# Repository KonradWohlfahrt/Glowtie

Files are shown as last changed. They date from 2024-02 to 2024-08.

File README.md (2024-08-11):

# Glowtie
This repository contains the project files for the Glowtie, a bowtie with individually addressable LEDs.
It was originally designed by [Stephen Hawes](https://github.com/sphawes/glowtie).
At the beginning, I used [Raxathor's](https://github.com/raxathor/GlowTie) adaptation.
Due to the lack of documentation, especially where to place the smd components, it was a real struggle to build it. Furthermore, I discovered issues with the design and thus settled on creating my own version.
In the following, I'm going to explain how you can build Raxathor's adaptation and of course mine!
Let's get started!

***
# Raxathor's Adaptation
Check out the instructable from [Raxathor](https://www.instructables.com/GlowTie/).

**Materials:**
| Component |  Amount  |
|:---|---:|
| custom pcb | 1 |
| lipo battery (max size: 20 x 30 x 7mm) | 1 |
| ESP-12F | 1 |
| TP4056A | 1 |
| DW01-A | 1 |
| FS8205A | 1 |
| TC2117-3.3V ~~AMS1117 3.3V~~ | 1 |
| SMD Power Slide Switch | 1 |
| Micro USB | 1 |
| WS2812b LEDs (Neopixel) | 13 |
| 10k 0805 | 5 |
| 1k 0805 | 3 |
| 100r 0805 | 1 |
| 10k ~~1.2k~~ 0805 (charge progamming resistor, check TP4056A datasheet) | 1 |
| red LED 0805 | 1 |
| green LED 0805 | 1 |
| 0.1uF 0805 | 2 |
| 10uF 0805 | 2 |
| 1uF 0805 | 1 |
| 100uF 1206 | 1 |

**Soldering:**
Solder the components to the indicated boxes on the images.
Make sure to program your chip in advance or add some programming cables to the back.
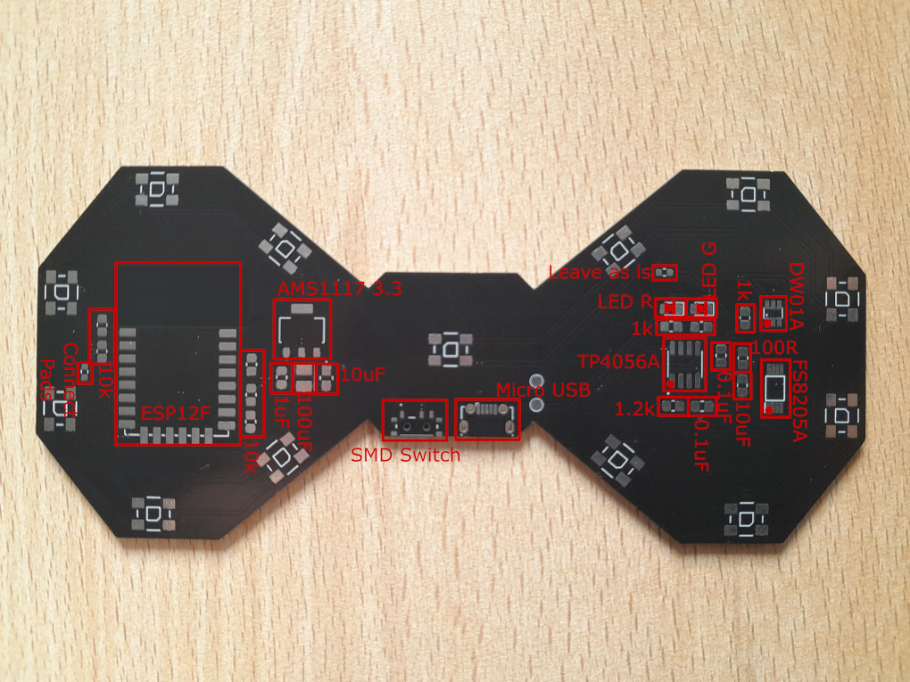
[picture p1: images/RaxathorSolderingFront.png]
Soldering Front

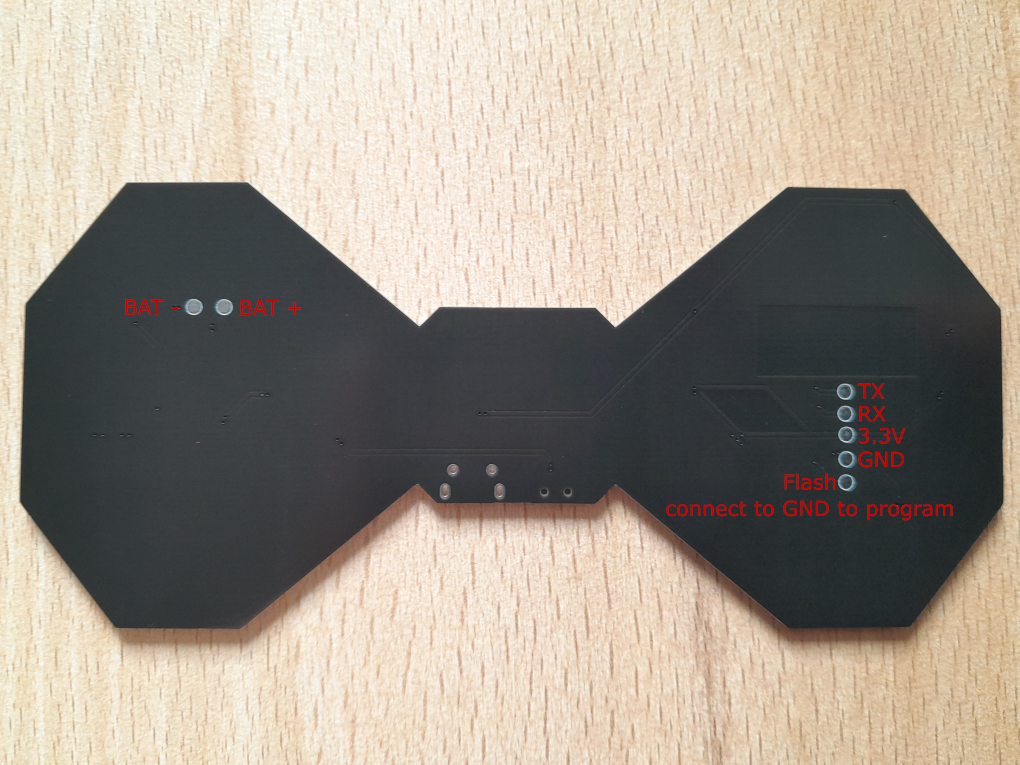
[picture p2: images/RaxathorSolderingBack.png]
Soldering Back


**Issues:**
During my tests I discovered a few flaws with the design.

First of all, the AMS1117 LDO has a too high dropout voltage.
This LDO is not suitable for powering the bowtie!
My alternative is the TC2117. Stephen Hawes used an MCP1826S with only 250mV of dropout. 
However, the pinout of this LDO does not fit on Raxathor's pcb.

Furthermore, soldering with a soldering iron was possible but challenging.
Especially with the small pins of the FS8205A Mosfet.
My smd switches (I've tried muliple) wouldn't always work correctly.
I also had issues with the 3d printed case, as it was not able to secure the pcb for a long amount of time.

***
# My Adaptation
That's why I created my own Glowtie. Those are all the changed I made:
- replaced charging circuit with popular charging board (easier to solder)
- added PH2.0 connector for LiPo battery
- replaced smd with through-hole switch
- added holes for M3 screws to secure the pcb on the 3d print
- new LDO (MIC39100), identical to the pinout of the one used by Stephen Hawes
- voltage divider to measure the voltage of the LiPo battery
- resistor from esp to first led, to prevent damage by high current
- added a button
- better programming pins
- every led has its own capacitor as recommended in the datasheet

However, I've recently discovered a flaw with my design.
The bowtie is not balanced, as the weight of the battery drags it down.
You should put some small objects of equal size inside the other hole.

**Materials:**
| Component | Amount | Silkscreen label |
|:---|:---:|---:|
| custom pcb | 1 | - |
| lipo battery (max size: width=30 x depth=40 x height=7mm) | 1 | - |
| ESP-12F | 1 | U4 |
| LiPo charge board | 1 | U3 |
| MIC39100 | 1 | U5 |
| Switch | 1 | U1 |
| button | 1 | U7 |
| Micro USB | 1 | U2 |
| WS2812b LEDs (Neopixel) | 13 | LED1 - LED13 |
| 100nF 0805 | 14 | C1 - C13, C17 |
| 10uF 0805 | 1 | C14 |
| 1uF 0805 | 1 | C15 |
| 100uF 1206 | 1 | C16 |
| 10k 0805 | 6 | R1 - R4, R6, R8 |
| 33k 0805 | 1 | R5 |
| 220r 0805 | 1 | R7 |
| PH2.0 2p (not recommended -> takes up space) | 1 | U6 |
| 90 degree connector 5p | 1 | - |
| 3d printed case | 1 | - |
| M3x8 screw with nut | 2 | - |

**Soldering:**
Solder the components as indicated in the table and images.
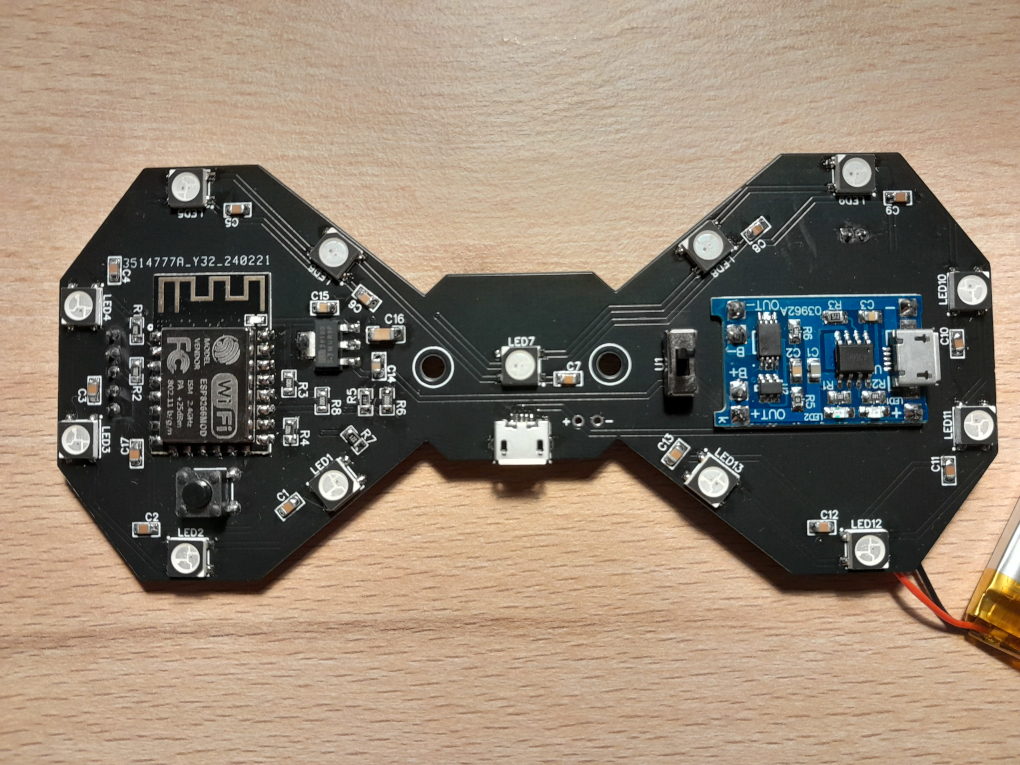
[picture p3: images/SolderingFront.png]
Soldering Front

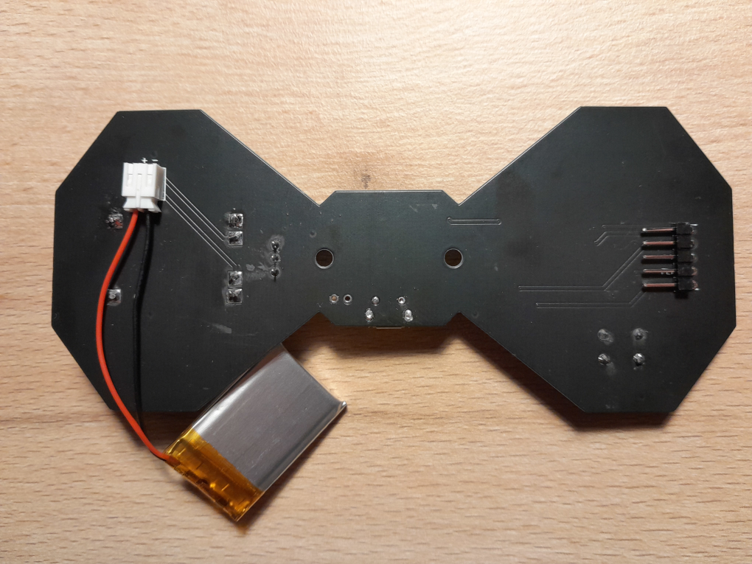
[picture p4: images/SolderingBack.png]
Soldering Back

Also check your datasheet of the battery. The charging board is commonly used for 18650 batteries.
However, the charging current of 1A is not suitable for the batteries used here.
Here's a great [video](https://www.youtube.com/watch?v=6asCEBm4ZAw) showing how you can change the charging resistor (I've used 5.1k 0805).

***
# Programming (for both designs)
In the `src/` folder you'll find my versions of the source code for each pcb design.
Open `Glowtie.ino` and change the ssid and password of the access point to your preferences.
Install the `Adafruit Neopixel` library and the `ESP8266` board manager. For the board select: `NodeMCU 0.9 (ESP-12 Module)`.
Connect the Glowtie with a FTDI programmer (3.3V logic level) like this and upload the code:
- TX (Glowtie) => RX (FTDI)
- RX (Glowtie) => TX (FTDI)
- VCC (Glowtie) => VCC (FTDI)
- GND (Glowtie) => GND (FTDI)
- Flash (Glowtie) => GND (FTDI)
> If you did not connect flash to gnd, the chip will no be in programming-mode. In my design you may just hold down the button while plugging in the FTDI programmer.

***
# The end
Great, now you have yourself your own Glowtie!
There is an enclosure which you can print in a 3d-printer.
I've used two M3x8 screws to secure the pcb on the print.

Button functions:
- short press: show current battery percentage
- double press: toggle random mode (on: green flash, off: red flash)
- long press: save current mode and color to eeprom  

Remember to check out Stephen Hawes and Raxathor, as this repository is based on theirs.

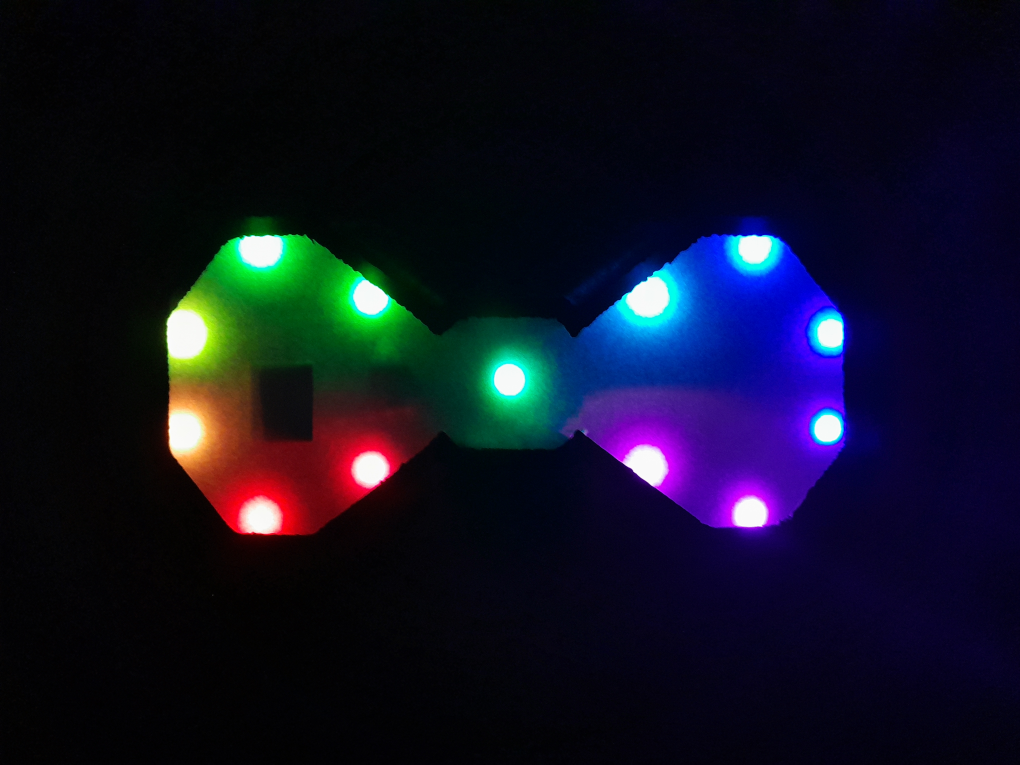
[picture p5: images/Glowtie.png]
Glowtie


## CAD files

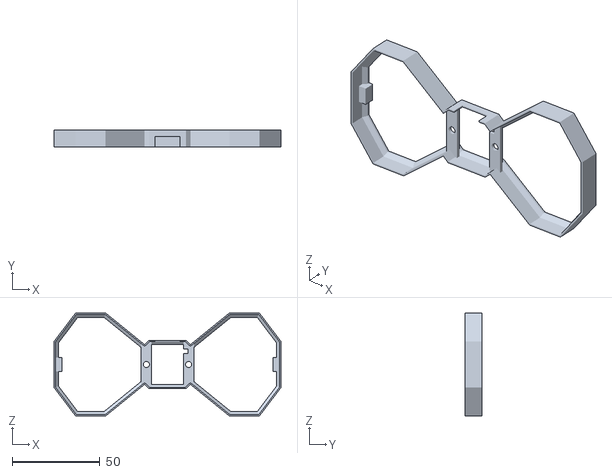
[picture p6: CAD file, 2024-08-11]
cad/Bumper.stl
129.0 x 9.75 x 58.5

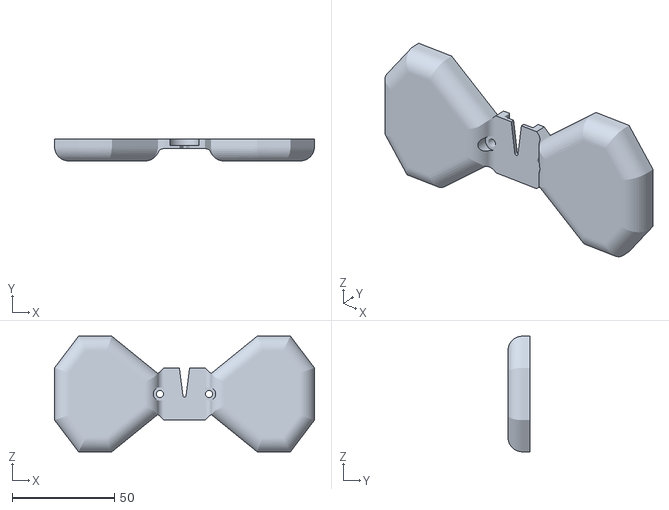
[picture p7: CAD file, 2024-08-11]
cad/Glowtie.stl
127.0 x 10.8 x 56.5

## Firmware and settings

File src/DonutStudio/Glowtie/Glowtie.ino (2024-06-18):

#include <Adafruit_NeoPixel.h>
#include <ESP8266WiFi.h>
#include <WiFiClient.h>
#include <ESP8266WebServer.h>
#include <EEPROM.h>

#include "webserver.h"

#define BUTTONPIN 0
#define SAVETIME 1500
#define DOUBLEPRESSINTERVAL 400

#define PIN 12
#define NUMPIXELS 13
#define EFFECTREFRESHTIME 75

#define BATTCHECKTIME 10000
#define BATTREADINGS 10

#define LOWBATTERYVALUE 825
#define SHUTDOWNVALUE 815


const char *ssid = "Glowtie";
const char *password = "pleaseletmein";

const uint32_t red = 0xff0000;
const uint32_t green = 0x00ff00;

const byte brightness[] = { 10, 20, 30, 40 };
const unsigned long randomTimeMin[] = { 120000, 60000, 30000, 10000 };
const unsigned long randomTimeMax[] = { 360000, 120000, 60000, 20000 };


Adafruit_NeoPixel pixels = Adafruit_NeoPixel(NUMPIXELS, PIN, NEO_GRB + NEO_KHZ800);
ESP8266WebServer server(80);


byte brightnessIndex = 1;


byte redValue = 127;
byte greenValue = 127;
byte blueValue = 127;

bool isRandomMode = false;
bool chooseRandomColor = false;
int speedIndex = 1;
unsigned long randomWait;
unsigned long lastRandomUpdate = 0;

unsigned long lastBatteryCheck = 0;
unsigned long lastEffectUpdate = 0;

unsigned long lastButtonPress = 0;
bool awaitingDoublePress = false;



/* --- UTILITY START --- */

float getVoltage() { return 4.3f / 1023 * analogRead(A0); } // formular: Vbat = (R6 + R5) / (R6 * 1023) * analogRead(A0)
int getBatteryPercent() { return (int)(((float)(analogRead(A0)) - LOWBATTERYVALUE) / (1023 - LOWBATTERYVALUE) * 100); }
bool checkBattery(int minimum)
{
  int avg = 0;
  for (byte b = 0; b < BATTREADINGS; b++)
  {
    avg += analogRead(A0);
    delay(2);
  }
  return (avg / BATTREADINGS) <= minimum;
}

/* --- UTILITY END --- */



#include "LedEffect.h"

#include "Solid.h"

#include "Breathe.h"
#include "Pulse.h"
#include "Bar.h"
#include "Burst.h"

#include "Infinity.h"
#include "Chaser.h"
#include "Circles.h"
#include "Symmetry.h"

#include "Starfield.h"
#include "Rainbow.h"
#include "Filler.h"

const byte effectCount = 19;
LedEffect * effects[] = { new Solid(), new SolidRainbow(),
                          new Breathe(), new Pulse(), new Bar(), new BurstIn(), new BurstOut(), 
                          new Infinity(), new InfinityFill(), new Chaser(), new ChaserFill(), new Circles(), new CirclesFill(), new Symmetry(), new SymmetryFill(),
                          new Starfield(), new Rainbow(), new RainbowFill(), new Filler() };
byte modeIndex = 0;
int effectCounter = 0;

void setup() 
{
  pinMode(A0, INPUT);
  pinMode(BUTTONPIN, INPUT);


  EEPROM.begin(7);
  delay(250);
  modeIndex = constrain(EEPROM.read(0), 0, effectCount - 1);
  redValue = EEPROM.read(1);
  greenValue = EEPROM.read(2);
  blueValue = EEPROM.read(3);

  chooseRandomColor = EEPROM.read(4) == 0;
  speedIndex = constrain(EEPROM.read(5), 0, 3);
  brightnessIndex = constrain(EEPROM.read(6), 0, 3);


  pixels.begin();
  pixels.setBrightness(brightness[brightnessIndex]);

  // ssid, password, default channel, do not hide ssid, one simultaneous connections
  if (WiFi.softAP(ssid, password, 1, false, 1)) 
    scrollAnim(green);
  else
    flashAnim(red);

  server.on("/", handleRoot);
  server.on("/red", handleGetRed);
  server.on("/green", handleGetGreen);
  server.on("/blue", handleGetBlue);
  server.on("/mode", handleGetMode);
  server.on("/vcc", handleGetVCC);
  server.on("/color", handleGetRandomColor);
  server.on("/speed", handleGetSpeed);
  server.on("/brightness", handleGetBrightness);
  server.begin();

  startEffect();
}
void loop() 
{
  server.handleClient();

  if (millis() - lastBatteryCheck >= BATTCHECKTIME) 
  {
    if (checkBattery(LOWBATTERYVALUE))
    {
      WiFi.mode(WIFI_OFF);
      flashAnim(red);
      lowBattery();
      while (true)
      {
        // turn everything off
        if (checkBattery(SHUTDOWNVALUE))
        {
          disableLEDs();
          ESP.deepSleep(0);
        }
        delay(5);
      }
    }

    lastBatteryCheck = millis();
  }


  handleEffects();


  if (digitalRead(BUTTONPIN) == 0)
  {
    bool shortPress = true;
    unsigned long started = millis();
    while (digitalRead(BUTTONPIN) == 0) 
    {
      handleEffects();

      if (shortPress && millis() - started >= SAVETIME)
      {
        shortPress = false;
        flashAnim(green);
        EEPROM.write(0, modeIndex);
        EEPROM.write(1, redValue);
        EEPROM.write(2, greenValue);
        EEPROM.write(3, blueValue);
        EEPROM.commit();
        delay(250);
      }
      
      delay(5);
    }

    if (shortPress)
    {
      if (!awaitingDoublePress)
      {
        awaitingDoublePress = true;
        lastButtonPress = millis();
      }
      else if (millis() - lastButtonPress < DOUBLEPRESSINTERVAL)
      {
        setRandomMode(!isRandomMode);
        awaitingDoublePress = false;
      }
    }
  }
  if (awaitingDoublePress && millis() - lastButtonPress >= DOUBLEPRESSINTERVAL)
  {
    awaitingDoublePress = false;
    showBatteryPercentage();
    startEffect();
  }

  if (isRandomMode)
  {
    if (millis() - lastRandomUpdate >= randomWait)
    {
      if (chooseRandomColor)
      {
        uint32_t col = getRandomColor();
        redValue = col >> 16;
        greenValue = col >> 8;
        blueValue = (byte)col;
      }
      
      int m;
      do {
        m = random(0, effectCount);
      } while (m == modeIndex);
      modeIndex = m;
      randomWait = random(randomTimeMin[speedIndex], randomTimeMax[speedIndex]);
      lastRandomUpdate = millis();
      startEffect();
    }
  }
}

void startEffect()
{
  pixels.clear();
  effectCounter = 0;
  effects[modeIndex]->onStart();
}
void handleEffects()
{
  if (!effects[modeIndex]->getIsStatic() && millis() - lastEffectUpdate >= effects[modeIndex]->getSpeed())
  {
    effects[modeIndex]->onUpdate(effectCounter);
    effectCounter++;
    lastEffectUpdate = millis();
  }
}
void setRandomMode(bool value)
{
  isRandomMode = value;
  flashSingleAnim(isRandomMode ? green : red);
  if (isRandomMode)
  {
    lastRandomUpdate = millis();
    randomWait = random(randomTimeMin[speedIndex], randomTimeMax[speedIndex]);
  }
  else
  {
    modeIndex = constrain(EEPROM.read(0), 0, effectCount - 1);
    redValue = EEPROM.read(1);
    greenValue = EEPROM.read(2);
    blueValue = EEPROM.read(3);
  }

  startEffect();
}


/* --- HTML --- */

void handleGetRed() { server.send(200, "text/plane", String(redValue)); }
void handleGetGreen() { server.send(200, "text/plane", String(greenValue)); }
void handleGetBlue() { server.send(200, "text/plane", String(blueValue)); }
void handleGetMode() { server.send(200, "text/plane", String(modeIndex)); }
void handleGetVCC() { server.send(200, "text/plane", String(getBatteryPercent()) + "% (" + String(getVoltage(), 2) + "V)"); }
void handleGetRandomColor() { server.send(200, "text/plane", (chooseRandomColor ? "1" : "0")); }
void handleGetSpeed() { server.send(200, "text/plane", String(speedIndex)); }
void handleGetBrightness() { server.send(200, "text/plane", String(brightnessIndex)); }
void handleRoot() 
{
  if (server.args() > 0) 
  {
    if (server.hasArg("red"))
    {
      redValue = (byte)server.arg("red").toInt();
      greenValue = (byte)server.arg("green").toInt();
      blueValue = (byte)server.arg("blue").toInt();
      modeIndex = (byte)server.arg("mode").toInt();

      isRandomMode = false;

      server.send(200, "text/html", index_html);

      startEffect();
    }
    else
    {
      chooseRandomColor = server.hasArg("randomcolor");
      EEPROM.write(4, chooseRandomColor ? 0 : 255);
      speedIndex = constrain(server.arg("speed").toInt(), 0, 3);
      EEPROM.write(5, speedIndex);
      brightnessIndex = constrain(server.arg("brightness").toInt(), 0, 3);
      EEPROM.write(6, brightnessIndex);

      if (pixels.getBrightness() != brightness[brightnessIndex])
        pixels.setBrightness(brightness[brightnessIndex]);

      server.send(200, "text/html", index_html);
  
      flashAnim(green);
      EEPROM.commit();
      delay(250);
      
      startEffect();
    }
  }
  else
    server.send(200, "text/html", index_html);
}

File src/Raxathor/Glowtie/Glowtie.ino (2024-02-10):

#include <Adafruit_NeoPixel.h>
#include <ESP8266WiFi.h>
#include <WiFiClient.h>
#include <ESP8266WebServer.h>
#include <EEPROM.h>
#include "webserver.h"

#define PIN            12
#define NUMPIXELS      13
#define EFFECTREFRESHTIME 75

#define BATTCHECKTIME 5000
#define BATTREADINGS 4

// change this according to your tests. AMS1117: 3100, TC2117: 3450
#define LOWBATTERYVALUE 3450
// change this according to your tests. AMS1117: 3050, TC2117: 3420
#define DISABLEVALUE 3420

#define USEEEPROM true

const char *ssid = "Glowtie";
const char *password = "pleaseletmein";


ADC_MODE(ADC_VCC);
enum GlowtieMode
{
  // STATIC
  OFF = 0,
  SOLID = 1,
  TIE = 2,

  // DYNAMIC
  BREATHE = 3,
  PULSE = 4,
  BAR = 5,
  BURSTIN = 6,
  BURSTOUT = 7,

  INFINITYCIRCLE = 8,
  INFINITYCIRCLEFILL = 9,
  CHASER = 10,
  CHASERFILL = 11,
  CIRCLES = 12,
  CIRCLESFILL = 13,
  SYMMETRY = 14,
  SYMMETRYFILL = 15,
  
  STARFIELD = 16,
  RAINBOW = 17,
  FILLER = 18
};
const byte infinityeffect[] = { 0, 1, 2, 3, 4, 5, 6, 12, 11, 10, 9, 8, 7, 6 };
const byte chasereffect[] = { 0, 1, 2, 3, 4, 5, 6, 7, 8, 9, 10, 11, 12, 6 };
const byte circleseffect[] = { 6, 0, 1, 2, 3, 4, 5, 6, 12, 11, 10, 9, 8, 7 };
const byte symmetryeffect[] = { 6, 0, 1, 2, 3, 4, 5, 6, 7, 8, 9, 10, 11, 12 };
const byte bareffect[] = { 2, 1, 0, 6, 12, 11, 10, 3, 4, 5, 6, 7, 8, 9 };


Adafruit_NeoPixel pixels = Adafruit_NeoPixel(NUMPIXELS, PIN, NEO_GRB + NEO_KHZ800);
ESP8266WebServer server(80);

GlowtieMode mode = SOLID;
unsigned long lastBatteryCheck = 0;


byte redValue = 127;
byte greenValue = 127;
byte blueValue = 127;

unsigned long lastEffectUpdate = 0;
int effectIndex = 0;

byte lastPixel = 0;
long firstPixelHue = 0;

uint32_t halfColor;
uint32_t randomColor;

byte randomRed;
byte randomGreen;
byte randomBlue;
bool isRandomPhase = false;


void setup() 
{
  pixels.begin();
  pixels.setBrightness(20);

  lowBattery();

  if (USEEEPROM)
  {
    EEPROM.begin(4);
    delay(500);

    mode = (GlowtieMode)EEPROM.read(0);
    redValue = EEPROM.read(1);
    greenValue = EEPROM.read(2);
    blueValue = EEPROM.read(3);
  }

  if (WiFi.softAP(ssid, password)) 
    successAnim();
  else 
    errorAnim();

  server.on("/", handleRoot);
  server.on("/red", handleGetRed);
  server.on("/green", handleGetGreen);
  server.on("/blue", handleGetBlue);
  server.on("/vcc", handleGetVCC);
  server.begin();

  delay(100);

  updatePixels();
}
void loop() 
{
  server.handleClient();

  // check battery
  if (millis() - lastBatteryCheck >= BATTCHECKTIME) 
  {
    if (hasLowBattery(LOWBATTERYVALUE))
    {
      WiFi.mode(WIFI_OFF);
      errorAnim();
      lowBattery();
      while (true) 
      {
        // turn everything off
        if (hasLowBattery(DISABLEVALUE))
        {
          disableDisplay();
          ESP.deepSleep(0);
        }
        delay(5);
      }
    }

    lastBatteryCheck = millis();
  }

  // refresh the dynamic effects
  if (millis() - lastEffectUpdate >= EFFECTREFRESHTIME)
  {
    switch (mode)
    {
      case BREATHE:
        breathe();
        break;
      case PULSE:
        pulse();
        break;
      case BAR:
        bar();
        break;
      case BURSTIN:
        burstIn();
        break;
      case BURSTOUT:
        burstOut();
        break;

      case INFINITYCIRCLE:
        infinitycircle();
        break;
      case INFINITYCIRCLEFILL:
        infinitycirclefill();
        break;
      case CHASER:
        chaser();
        break;
      case CHASERFILL:
        chaserfill();
        break;
      case CIRCLES:
        circles();
        break;
      case CIRCLESFILL:
        circlesfill();
        break;
      case SYMMETRY:
        symmetry();
        break;
      case SYMMETRYFILL:
        symmetryfill();
        break;
      
      case STARFIELD:
        starfield();
        break;
      case RAINBOW:
        rainbow();
        break;
      case FILLER:
        filler();
        break;
    }
    effectIndex++;
    lastEffectUpdate = millis();
  }
}


/* --- HTML --- */

void handleGetRed() { server.send(200, "text/plane", String(redValue)); }
void handleGetGreen() { server.send(200, "text/plane", String(greenValue)); }
void handleGetBlue() { server.send(200, "text/plane", String(blueValue)); }
void handleGetVCC() { server.send(200, "text/plane", "ADC: " + String(ESP.getVcc())); }
void handleRoot() 
{
  if (server.args() > 0) 
  {
    redValue = (byte)server.arg("red").toInt();
    greenValue = (byte)server.arg("green").toInt();
    blueValue = (byte)server.arg("blue").toInt();
    mode = (GlowtieMode)server.arg("mode").toInt();

    if (USEEEPROM)
    {
      EEPROM.write(0, (byte)mode);
      EEPROM.write(1, redValue);
      EEPROM.write(2, greenValue);
      EEPROM.write(3, blueValue);
      EEPROM.commit();
      delay(250);
    }

    updatePixels();
  }

  server.send(200, "text/html", index_html);
}


/* --- UTILITY --- */

bool hasLowBattery(int minimum)
{
  int avg = 0;
  for (byte b = 0; b < BATTREADINGS; b++)
  {
    avg += ESP.getVcc();
    delay(25);
  }
  avg /= BATTREADINGS;

  return avg <= minimum;
}
void updatePixels()
{
  effectIndex = 0;
  pixels.clear();
  switch (mode)
  {
    case OFF:
      disableDisplay();
      break;
    case SOLID:
      solid();
      break;
    case TIE:
      tie();
      break;
    case BAR:
      randomColor = pixels.Color(redValue, greenValue, blueValue);
      halfColor = pixels.Color(redValue / 2, greenValue / 2, blueValue / 2);
      break;
    case FILLER:
      isRandomPhase = false;
      randomColor = pixels.Color(redValue, greenValue, blueValue);
      break;
  }
}
void successAnim()
{
  for (int i = 0; i < NUMPIXELS; i++)
  {
    pixels.setPixelColor(i, 0, 255, 0);
    pixels.show();
    delay(EFFECTREFRESHTIME);
  }
  for (int i = 0; i < NUMPIXELS; i++)
  {
    pixels.setPixelColor(i, 0, 0, 0);
    pixels.show();
    delay(EFFECTREFRESHTIME);
  }
}
void errorAnim()
{
  for (int i = 0; i < 10; i++)
  {
    if (i % 2 == 0)
      pixels.fill(pixels.Color(255, 0, 0));
    else
      pixels.clear();
    
    pixels.show();
    delay(EFFECTREFRESHTIME);
  }
}
byte getAverage(byte a, byte b)
{
  return (byte)(((int)a + (int)b) / 2);
}
byte shiftByte(byte a, byte shift)
{
  if (shift > a || a > 255 - shift)
    return a;
  return a + random(-shift, shift + 1);
}
byte getShift(byte c)
{
  int shift = c / 2;
  if (c > 127)
    shift = (255 - c) / 2;

  return shiftByte(c, shift);
}
void setBar(byte index, uint32_t color)
{
  if (0 > index || index > 6)
    return;
  pixels.setPixelColor(bareffect[index], color);
  pixels.setPixelColor(bareffect[index + 7], color);
}


/* --- STATIC EFFECTS --- */

void lowBattery() 
{
  pixels.clear();
  pixels.setPixelColor(6, 50, 0, 0);
  pixels.show();
}
void disableDisplay()
{
  pixels.clear();
  pixels.show();
}
void solid()
{
  pixels.fill(pixels.Color(redValue, greenValue, blueValue));
  pixels.show();
}
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

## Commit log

2024-01-23 add: supply voltage reading from 6 values
2024-01-23 add: battery reading script
2024-01-23 update: low battery value, low battery effect
2024-01-23 update: low battery effect
2024-02-10 update battery test
2024-03-06 MAJOR UPDATE: added own pcb, stl and code for new pcb
    [Glowtie.stl, bumper.stl, frame.stl]
2024-03-07 update: readme.md, sketch for new pcb
2024-03-13 update glowtie stl
    [Glowtie.stl]
2024-03-24 update stl
    [Glowtie.stl]
2024-03-26 update: random mode; added: battery percent display; fixed: mode selection on html
    [Glowtie.ino]
2024-05-25 fix bug: random color only when selected
    [Glowtie.ino]
2024-05-25 update glowtie.stl, add bumper.stl
    [Bumper.stl, Glowtie.stl]
2024-06-10 fix bug when disabling random mode, update random color
    [Glowtie.ino]
2024-06-10 update battery reading functions
2024-06-18 update battery read and display
2024-08-11 update readme.md, update cad
2024-08-11 update cad
    [Bumper.stl, Glowtie.stl]
